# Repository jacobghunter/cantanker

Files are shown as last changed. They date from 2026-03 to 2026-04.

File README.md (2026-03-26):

This is a split wireless keyboard running ZMK with custom PCB and case designs



## Tools/software Used:
- [Ergogen](https://github.com/ergogen/ergogen) for layout and PCB generation as well as DXF files for case design
- [KiCad](https://www.kicad.org/) to wire the PCB
- [FreeCAD](https://www.freecad.org/) for case and plate design
- [ZMK](https://zmk.dev/) for the wireless firmware
- A slightly modified version of [this](https://github.com/AYM1607/zmk-driver-azoteq-iqs5xx) trackpad firmware by AYM1607

A big thank you to all the awesome people who have contributed to these projects, all of this being free and open source is truly amazing!

Its main features are:
- Bluetooth low energy connectivity
- Azotec TPS43 trackpad mounted on the right side
- 5000mAh batteries in each side
- Dual rotary encoders
- Nice! View display
- Low profile with choc v1 switches

## PCB Renders
| Side | Top | Bottom |
| :--- | :---: | :---: |
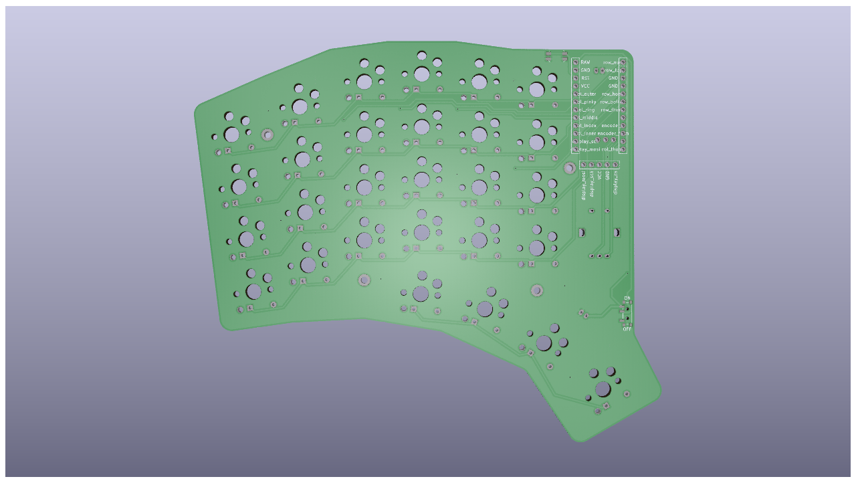
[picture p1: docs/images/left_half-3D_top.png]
Left Top
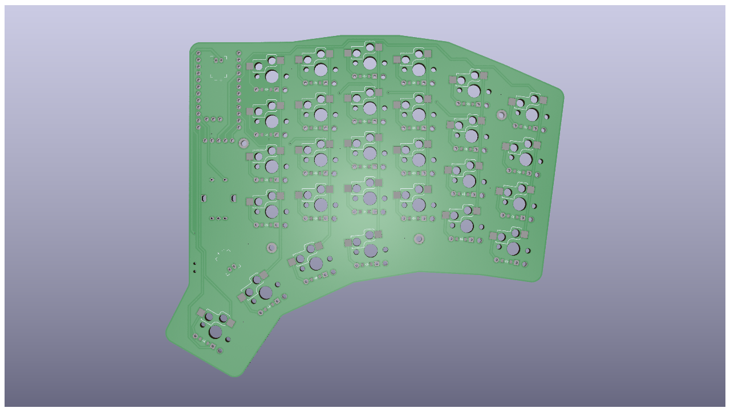
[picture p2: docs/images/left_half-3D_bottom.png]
Left Bottom
| **Left Half** |  |  |
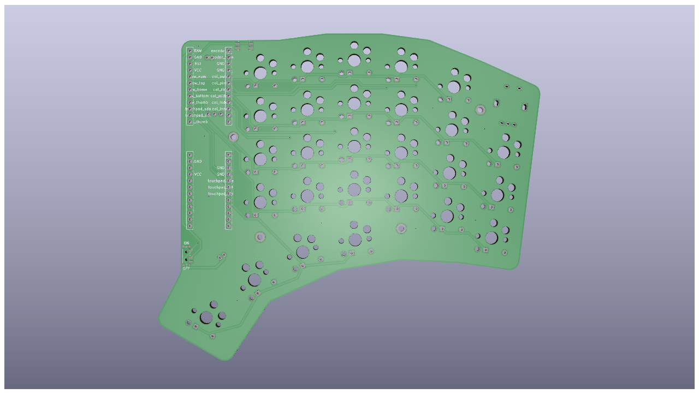
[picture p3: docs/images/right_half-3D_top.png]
Right Top
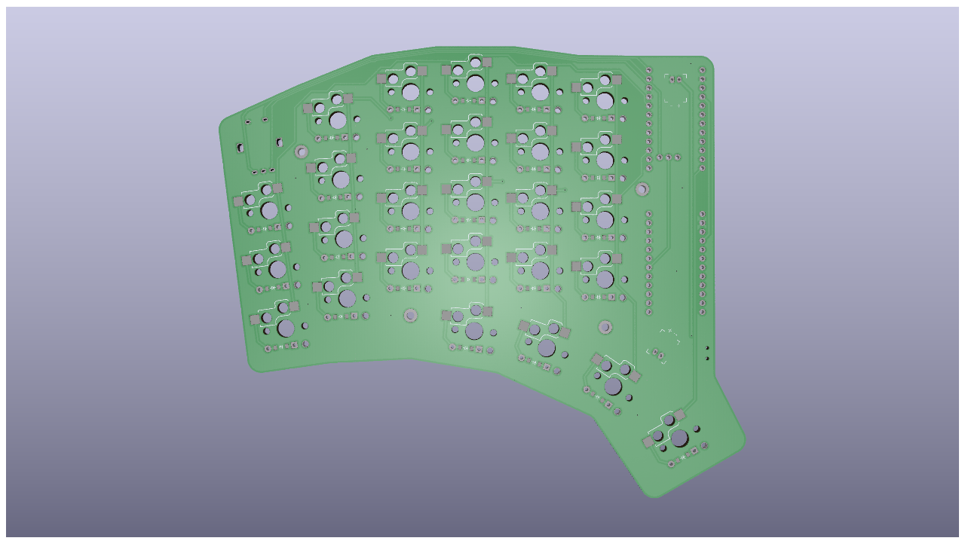
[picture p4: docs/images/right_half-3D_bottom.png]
Right Bottom
| **Right Half** |  |  |

You can find the source FCStd file for the case and plates [here](mechanical/Cantanker_Case_and_Plates.FCStd) and print-ready exports below:
| Part | STLs | STEPs |
| :--- | :--- | :--- |
| **Left Case** | [Download](mechanical/exports/Cantanker_Left_Case.stl) | [Download](mechanical/exports/Cantanker_Left_Case.step) |
| **Right Case** | [Download](mechanical/exports/Cantanker_Right_Case.stl) | [Download](mechanical/exports/Cantanker_Right_Case.step) |
| **Left Plate** | [Download](mechanical/exports/Cantanker_Left_Plate.stl) | [Download](mechanical/exports/Cantanker_Left_Plate.step) |
| **Right Plate** | [Download](mechanical/exports/Cantanker_Right_Plate.stl) | [Download](mechanical/exports/Cantanker_Right_Plate.step) |

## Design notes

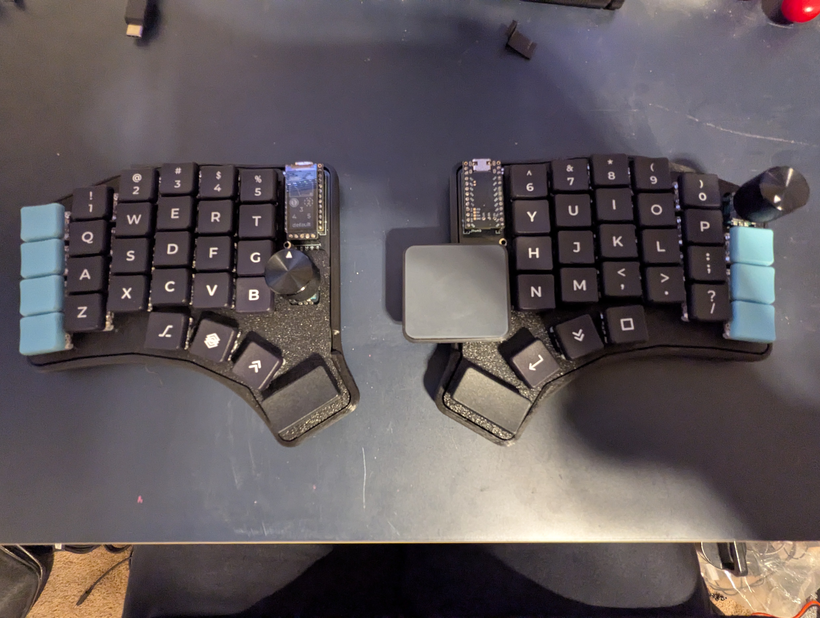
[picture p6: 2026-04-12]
docs/images/new_case.jpg

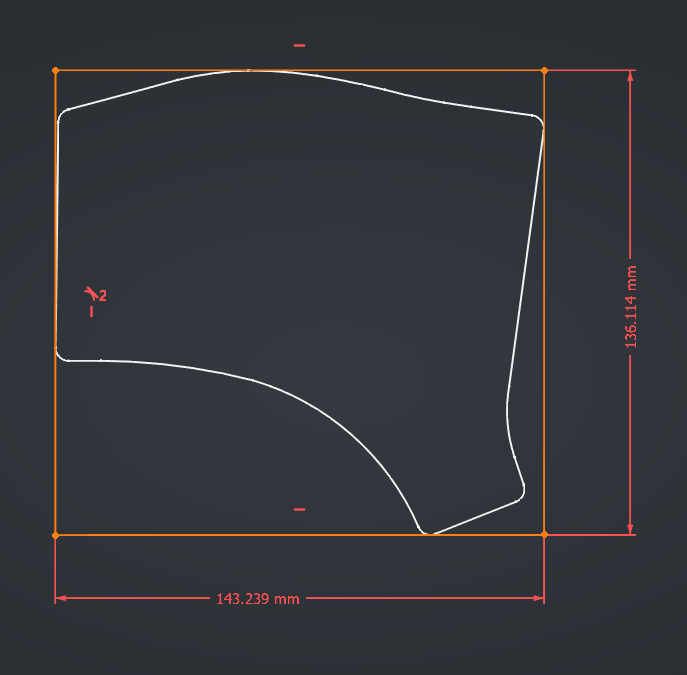
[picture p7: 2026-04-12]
docs/images/new_case_dimesions.png

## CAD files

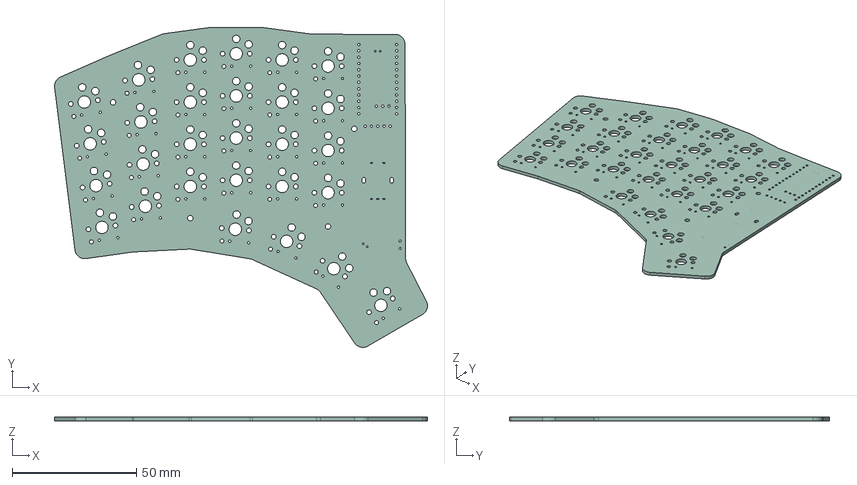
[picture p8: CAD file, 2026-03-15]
kicad/left_half.step
150.3 x 128.8 x 1.51 mm

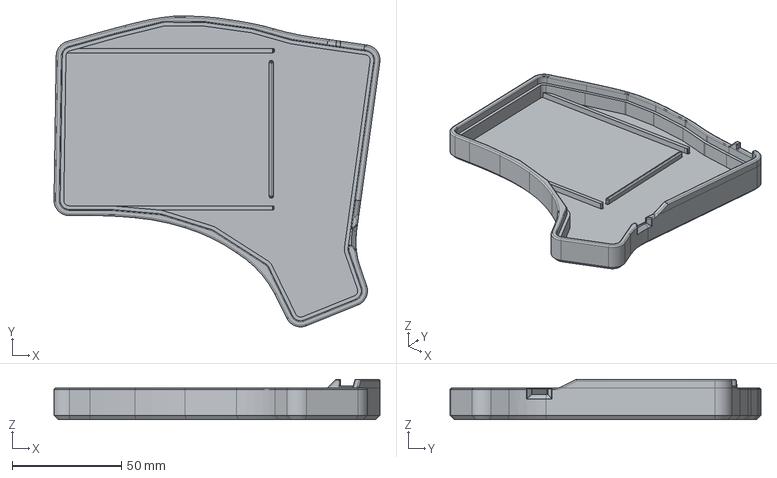
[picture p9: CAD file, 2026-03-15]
mechanical/exports/Cantanker_Left_Case.step
149.3 x 142.3 x 18.5 mm

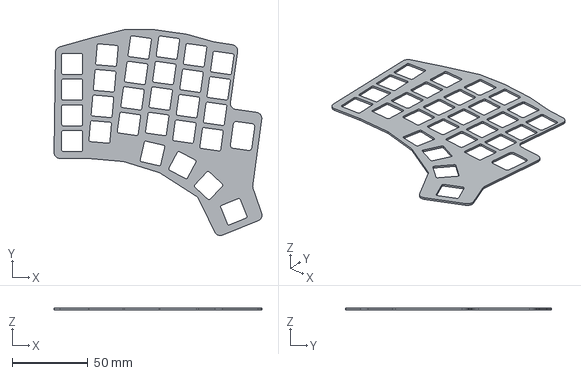
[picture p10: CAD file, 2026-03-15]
mechanical/exports/Cantanker_Left_Plate.step
137.5 x 136.3 x 1.20 mm

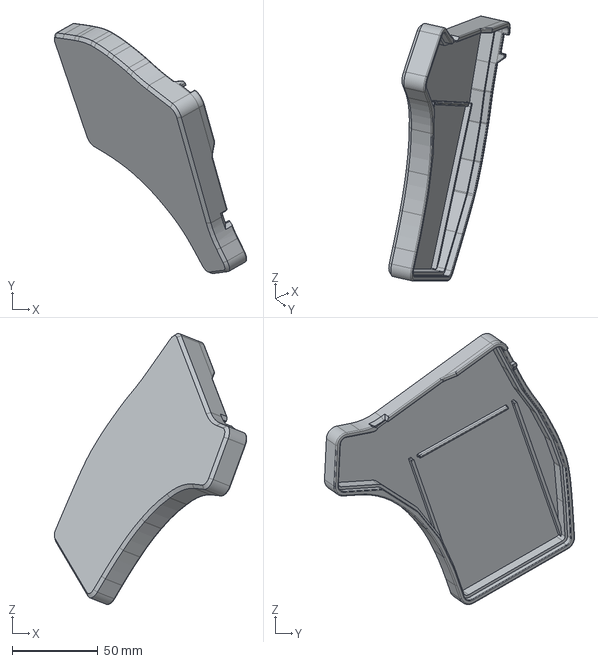
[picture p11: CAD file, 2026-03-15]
mechanical/exports/Cantanker_Right_Case.step
112.4 x 146.1 x 158.3 mm

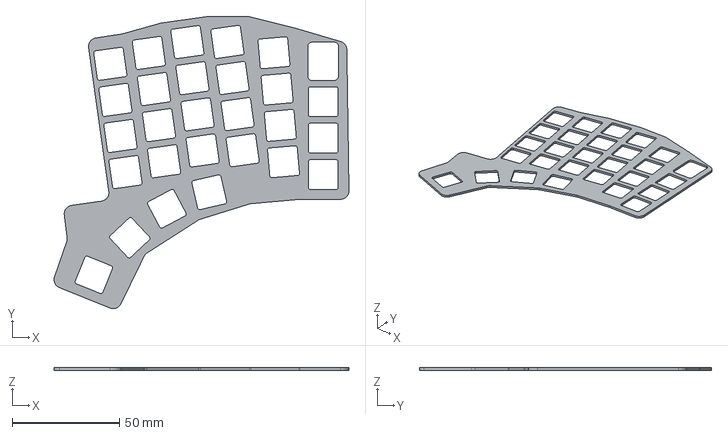
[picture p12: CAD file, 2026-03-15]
mechanical/exports/Cantanker_Right_Plate.step
137.5 x 136.3 x 1.20 mm

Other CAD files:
mechanical/exports/Cantanker_Left_Plate.stl
mechanical/exports/Cantanker_Right_Case.stl
mechanical/exports/Cantanker_Right_Plate.stl

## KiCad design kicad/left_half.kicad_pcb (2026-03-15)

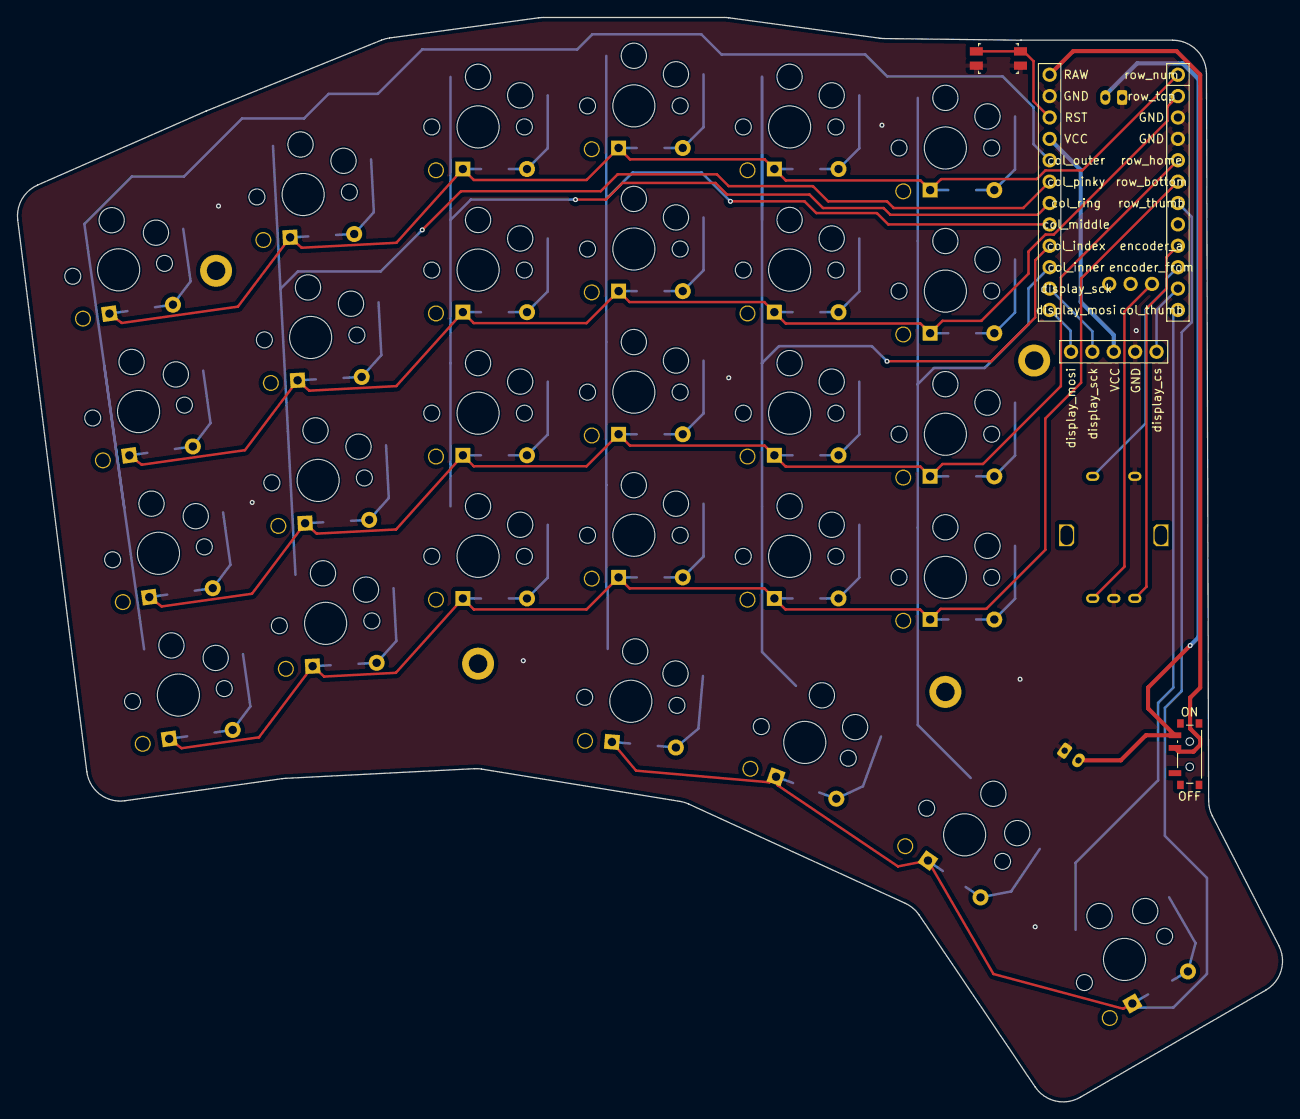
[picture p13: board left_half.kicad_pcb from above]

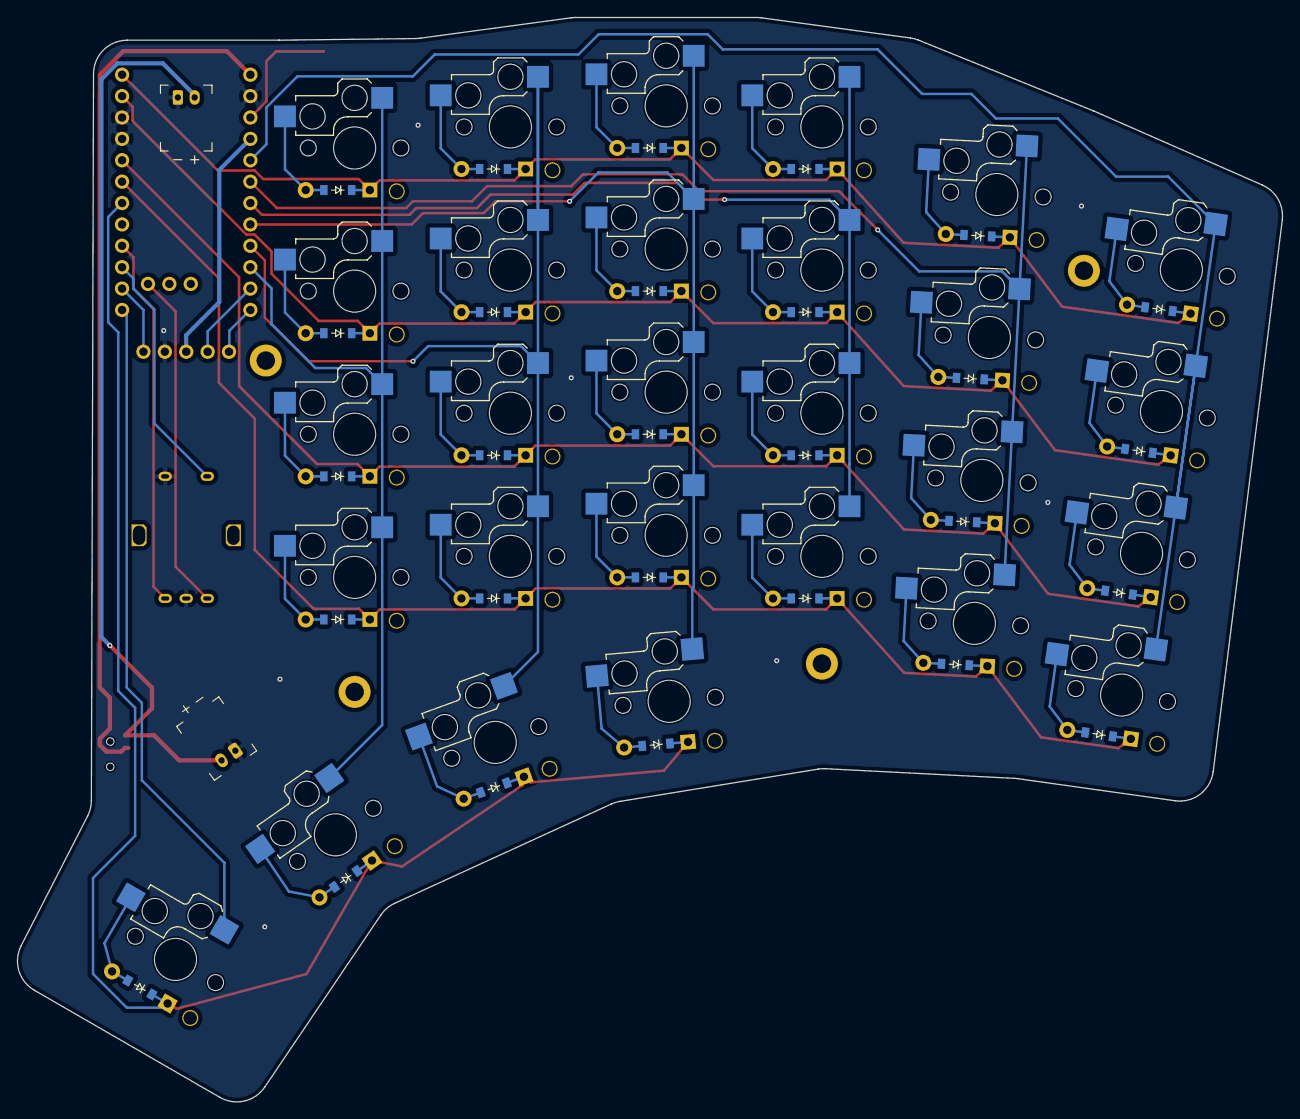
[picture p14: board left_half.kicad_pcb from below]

Board: 2 copper layers, 150.2 x 128.8 mm, 67 parts (58 on the bottom side), 51 nets.

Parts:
D1, D2, D3, D4, D5, D6, D7, D8, D9, D10, D11, D12, D13, D14, D15, D16, D17, D18, D19, D20, D21, D22, D23, D24, D25, D26, D27, D28: diode_tht_sod123
DISP1: display_nice_view
H1, H2, H3, H4: mounting_hole_plated
JST1, JST2: battery_connector_jst_ph_2
MCU1: mcu_supermini_nrf52840
PWR1: power_switch_smd_side
RE1: rotary_encoder_ec11_ec12
RST1: reset_switch_smd_side
S1, S2, S3, S4, S5, S6, S7, S8, S9, S10, S11, S12, S13, S14, S15, S16, S17, S18, S19, S20, S21, S22, S23, S24, S25, S26, S27, S28: switch_choc_v1_v2

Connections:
BAT_P: JST1.2, JST2.2, PWR1.3
GND: DISP1.4, JST1.1, JST2.1, MCU1.3, MCU1.4, MCU1.23, RE1.B, RE1.S2, RST1.2, RST1.4
RAW: MCU1.24, PWR1.2
RST: MCU1.22, RST1.1, RST1.3
VCC: DISP1.3, MCU1.21
col_index: MCU1.16, S17.1, S18.1, S19.1, S20.1, S28.1
col_inner: MCU1.15, S21.1, S22.1, S23.1, S24.1, S25.1
col_middle: MCU1.17, S13.1, S14.1, S15.1, S16.1, S27.1
col_outer: MCU1.20, S1.1, S2.1, S3.1, S4.1
col_pinky: MCU1.19, S5.1, S6.1, S7.1, S8.1
col_ring: MCU1.18, S9.1, S10.1, S11.1, S12.1
col_thumb: MCU1.12, S26.1
default_default: D28.2, S28.2
display_cs: DISP1.5, MCU1.11
display_mosi: DISP1.1, MCU1.13
display_sck: DISP1.2, MCU1.14
encoder_a: MCU1.9, RE1.A
encoder_b: MCU1.25, RE1.C
encoder_from: MCU1.10, RE1.S1
index_bottom: D17.2, S17.2
index_home: D18.2, S18.2
index_num: D20.2, S20.2
index_top: D19.2, S19.2
inner_bottom: D21.2, S21.2
inner_home: D22.2, S22.2
inner_num: D24.2, S24.2
inner_top: D23.2, S23.2
layer_cluster: D25.2, S25.2
middle_bottom: D13.2, S13.2
middle_home: D14.2, S14.2
middle_mod_default: D27.2, S27.2
middle_num: D16.2, S16.2
middle_top: D15.2, S15.2
outer_bottom: D1.2, S1.2
outer_home: D2.2, S2.2
outer_num: D4.2, S4.2
outer_top: D3.2, S3.2
pinky_bottom: D5.2, S5.2
pinky_home: D6.2, S6.2
pinky_num: D8.2, S8.2
pinky_top: D7.2, S7.2
ring_bottom: D9.2, S9.2
ring_home: D10.2, S10.2
ring_num: D12.2, S12.2
ring_top: D11.2, S11.2
row_bottom: D1.1, D5.1, D9.1, D13.1, D17.1, D21.1, MCU1.6
row_home: D2.1, D6.1, D10.1, D14.1, D18.1, D22.1, MCU1.5
row_num: D4.1, D8.1, D12.1, D16.1, D20.1, D24.1, MCU1.1
row_thumb: D25.1, D26.1, D27.1, D28.1, MCU1.7
row_top: D3.1, D7.1, D11.1, D15.1, D19.1, D23.1, MCU1.2
space_cluster: D26.2, S26.2

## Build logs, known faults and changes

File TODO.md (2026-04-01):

# Future improvements

- Trackpad emitting trackpad instead of mouse events, support gestures
- Trackpad mouse layer active while ready pin is on the trackpad, not just while moving it
- nice! view display showing both battery %s

## Case edits

- Edit case/plate to cover the MCU with an OLED screen hole
- edit plates to cover the bottom of the encoder (it's ugly)
- ~edit plates to have cutout for power switch~
- edit case to allow for plastic sheet to slot above battery
- ~magnetic feet attachment~
- use non-magneric route with slotting feet into the base -- can slide out of the edge of the case
- slots for straps in the bottom?
- Color switches to not be red and super obvious (fine tip sharpie?)
- make wider so rubber can grab correctly when wrapped around pcb
- also make the PCB plateau further down to account for rubber
- ridge on the inside above the plateau? super small inset into wall
- add brace for trackpad

# things 2 get

- heat gun?
- mounting plastic tape/plate

# Trackpad

- gestures via different branch: https://github.com/petejohanson/zmk/tree/feat/pointers-move-scroll-ptp
- currently the mouse layer deactivates when i stop moving my finger on the touchpad
  - figure out a way to emit an event when ready starts as active and emit another when it deactivates, having the mouse layer active the whole time
- Try to fix initial startup non-responsiveness
- Click to drag with second finger

# Ideas

Scroll wheel

- Do/undo
- arrow key navigation? Would use shift as a mod to do up/down and default to left/right?
- Swap tabs in browser/code
- Swap workspaces in hyprland/tabs in firefox based on layer with encoder?
- Zoom in/out (already done via mouse scroll with ctrl home mod)
- Start with larger scroll for mouse and adjust it by holding ctrl as a mod for it
- Fix expanded brace combos
- mouse layer when touchpad is active? so keys can be clicks?
- Arrow function combo?
- Add vim keystrokes?

Combos
Sticky keys/layers?
Gaming mode.
Positional Hold-Tap?

# Next time

- MCU on the bottom of the PCB?

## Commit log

2026-03-15 add kicad files
    [full_board.kicad_pcb, left_half.kicad_pcb, left_half.step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]
2026-03-15 add freecad file and exports
    [Cantanker_Left_Case.step, Cantanker_Left_Plate.step, Cantanker_Left_Plate.stl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]
2026-03-15 docs: update pcb renders for right_half [skip ci]
2026-03-15 docs: update pcb renders for left_half [skip ci]
2026-03-15 put pcb renders in readme
2026-03-15 update pcb render images
2026-03-15 update pcb render table
2026-04-12 new images of case
